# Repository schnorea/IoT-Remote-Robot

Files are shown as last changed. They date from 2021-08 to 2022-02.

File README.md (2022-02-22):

# IoT-Remote-Robot


This quick and dirty IoT enabled InfraRed Remote control is a way to remotely control a Robosapien Robot. It uses a web interface that looks like the remote control that comes with the Robosapien, AWS S3 to serve the web page, API Gateway receive the commands from the web remote, and processes these commands in a Lambda function that uses http to publish the command to an AWS IoT Core MQTT broker.  The Robot has a backpack that is 3D printed that hooks to its back.  Out of the backpack is a wire stalk that looks like a bent antenna that holds an IR LED and that connects to electronics in the backpack.  The IR stalk is pointed at the head of the Robosapien and directs the IR light to the IR receive located in the robots head.  Inside the backpack there is a driver circuit for the IR LED, a ESP8266 (Could easily be converted to a ESP32) that has a WIFI module. Flashed into the ESP8266 is firmware to access the local WIFI AP, create a secure connection to AWS IoT Core's MQTT broker and the logic to subscribe to the command messages originating in the Lambda function mentioned above. The backpack also contains the insides of a USB charging battery that has a lithium battery and the circuitry to charge from a 5 volt source and to provide 5 V to the ESP8266 and the IR LED. There are some diagrams, images and model renderings below.

## WARNING: This is a quick and dirty project. Normal engineering rigor and cyber security has not been applied here and your UX might vary.

## Background
During Covid my nephew, who lives across the state from me, was getting bored couped up at home with my sister. I would call and facetime and we would crack jokes to each other but couldn't really play together. I was thinking about how we could make it so we could remotely play and thought of those things in my house that could be remotely controlled.  I had gotten the Robosapien as a gag gift years ago for Christmas and this project was born.

## Remote Play Use Case
The way my nephew and I would use this is as follows.  
 * I would text my nephew the URL for the web remote.  
 * Once he had the remote up on his phone I would Facetime/Zoom him and he would answer on his iPad/Laptop. 
 * I would turn on the Robosapien and his IoT Backpack and let it connect to the Wifi and then to AWS.  When the backpack glowed blue (LED in the ESP8266) I knew it was connected.
 * I would give the thumbs up to my nephew and turn my phone with Facetime or laptop with Zoom running on it so that he could see the robot.
 * My nephew would then begin to control the robot remotely and laughing would ensue.

## Block Diagram
Here you can see the system block diagram.  

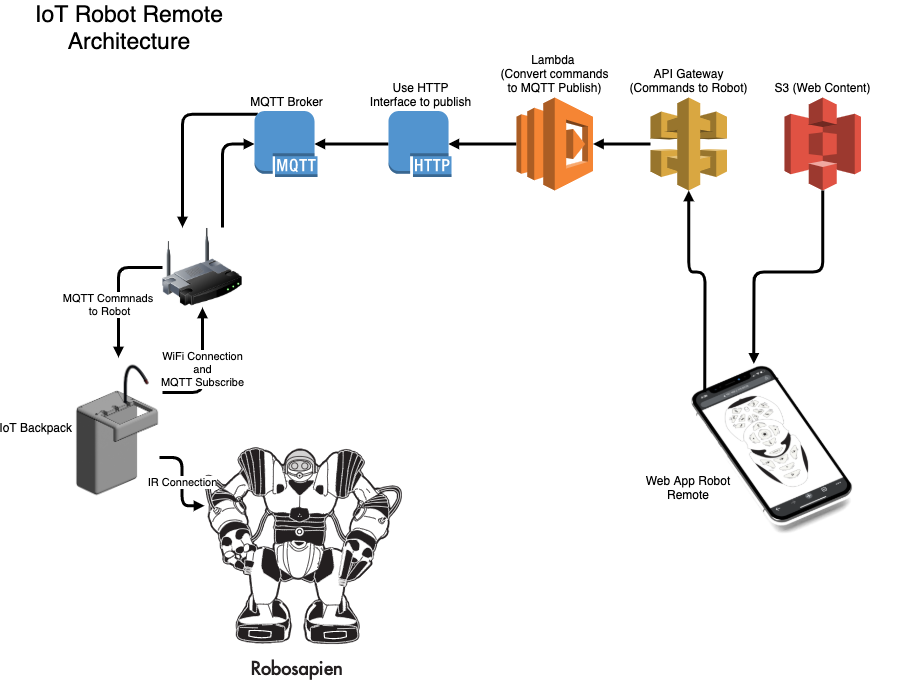
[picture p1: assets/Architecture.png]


## The Remote
The remote is assembled from very basic web tech.  HTML, SVG, Javascript, AJAX and a bit of CSS. Each button of the remote, in the SVG, has the code associated with the three modes the remote can be in attached.  With a click event the Javascript pulls the correct IR code from the button and performs a get to the AWS API Gateway.  You will need to setup your own API gateway for your own robot.  

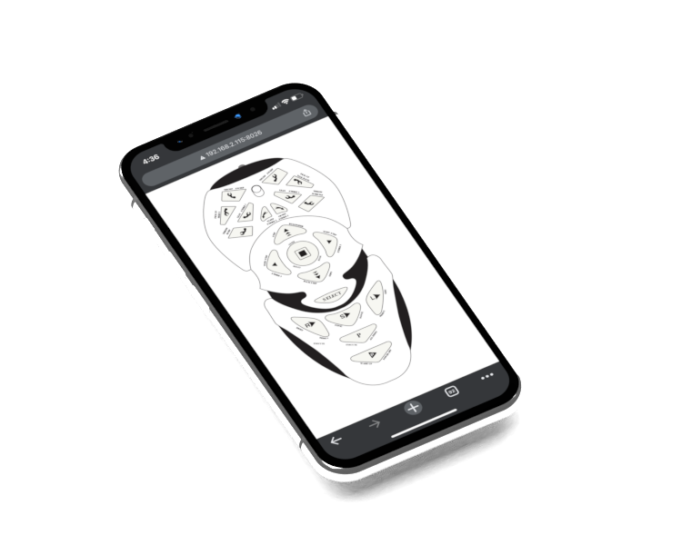
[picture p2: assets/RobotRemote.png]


## AWS
In AWS we use S3 to host and server the Web Remotes content.  S3 can be setup to server content by allowing it to be exposed publicly.  Again, this isn’t meant to be a product and is something that isn’t running all the time so quick and dirty.

Commands from the Web Remote are received via an API Gateway.  The gateway is configured to recognize the GET method which then triggers a Lambda function.

The Lambda function’s job is to take the Remote commands received via API Gateway and to publish them to the MQTT broker.  Yes, I could have cut out the Lambda function by doing MQTT over websockets but I didn’t want to have to have my Nephew have to sign-in to access the Web Remote.

The IoT Core MQTT broker is setup with a policy that allows commands to by publish and subscribed to.  It also has authentication and encryption enabled.  This is perhaps the most secure part of the pipeline. It also means that the backpack has to have credentials to communicate with the MQTT broker.

## The Backpack
As mentioned above the backpack is built around a ESP8266 Wifi module I ordered from Amazon (~$6.00).  Around the module are circuitry for the IR LED transmitter, a lithium battery and charging system I stole from a cell phone charging battery.  This is housed in a 3D printed case that was partially designed for this application and partially borrowed from a light dimming project.

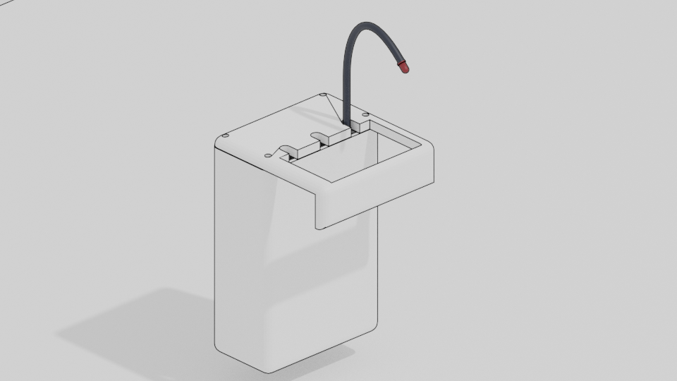
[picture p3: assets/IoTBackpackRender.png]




### The Ugly Electronics
Again as this was meant to be quick and dirty nothing elegent was designed to make this remotely pretty.  Old wire wrap board with hand soldered components and the piece de resistance(sp) the power supply assembly.







### Time to assemble.
As I had everything in the basement the hardware didn't take long to build. So, maybe 3 hours which included destroying the battery charger and making everything fit.

## Possible Improvements
 * The ESP8266 has barely enough computational power to run this app. I think the problem is the encryption overhead.  As a result of this the IoT backpack sometimes takes a long time to connect as it times out due to potentially poor comms making the computation take longer. (Anecdotally, it seems to connect better with a better WiFi signal). Improvement would be to port it to ESP32 which I don’t believe will have this problem.
 * I think there is just enough performance in an ESP32-CAM to do both the IoT function and stream the video so one idea would be to incorporate the video stream in the Web Remote interface.  This would simplify the use and also mean that the player would have a robot's eye view (First Person Robot?).
 * Make the Web Remote a true web app for iOS. On other projects I have done, if you add the correct meta fields and icons information into the web pages header you can create something that looks and feels a lot like a iPhone app without all the hassle of diving into XCode or other platforms. With a save to homepage bookmark from Saferi it presents itself as an ordinary app icon.

## Other uses
Since building this and having my nephew remotely come over and play a couple of other uses cases have presented themselves. 
 * Change channels of TV at home.  Why?
 * Turn on Air condition before getting home. Some AC units have IR remotes.
 * Attach it to other IR controlled toys.
 * IoT Slot cars.
 * If you have other ideas open an issue.

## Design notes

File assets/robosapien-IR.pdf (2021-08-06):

Interfacing a Robosapien with a mote

The commands to control the robosapien are sent from the IR transmitter to the receiver to the main control board as a sequence of 8 bits (most significant bit first). These bits are encoded using a space coded signal. The space coding works as follows:
- Default signal state: high
- Start: signal goes low for 8/1200 seconds
- Data bits (sequence of 8):
- 0: signal high for 1/1200s and low for 1/1200s
- 1: signal high for 4/1200s and low for 1/1200s

The IR control can be skipped by directly interfacing the microcontroller (mote) with the robosapien main control board.

Detailed | commands | from: | http://www.andrew.cmu.edu/user/ebuehl/robosapien-
lirc/ir_codes.htm

Movement Commands (no shift)

- $80 - turn right (on left side of remote)
- $81 - right arm up (upper left button on remote)
- $82 - right arm out
- $83 - tilt body right
- $84 - right arm down
- $85 - right arm in
- $86 - walk forward
- $87 - walk backward
- $88 - turn left (on right side of remote)
- $89 - left arm up (upper right button on remote)
- $8A - left arm out
- $8B - tilt body left
- $8C - left arm down
- $8D - left arm in
- $8E - stop

Programming Commands (no shift)

- $90 - P (Master Command Program)
- $91 - P>> (Program Play, the one on the bottom)
- $92 - R>> (Right sensor program)
- $93 - L>> (Left sensor program)
- $94 - S>> (Sonic sensor program)

GREEN shift commands

- $A0 - right turn step
- $A1 - right hand thump
- $A2 - right hand throw
- $A3 - sleep
- $A4 - right hand pickup
- $A5 - lean backward
- $A6 - forward step
- $A7 - backward step
- $A8 - left turn step
- $A9 - left hand thump
- $AA - left hand throw
- $AB - listen
- $AC - left hand pickup
- $AD - lean forward
- $AE - reset
- $B0 - Execute (master command program execute)

- $B1 - Wakeup
- $B2 - Right (right sensor program execute)
- $B3 - Left (left sensor program execute)
- $B4 - Sonic (sonic sensor program execute)

ORANGE shift commands

- $C0 - right hand strike 3
- $C1 - right hand sweep
- $C2 - burp
- $C3 - right hand strike 2
- $C4 - high 5
- $C5 - right hand strike 1
- $C6 - bulldozer
- $C7 - oops (fart)
- $C8 - left hand strike 3
- $C9 - left hand sweep
- $CA - whistle
- $CB - left hand strike 2
- $CC - talkback
- $CD - left hand strike 1
- $CE - roar
- $D0 - All Demo
- $D1 - Power Off (drop snow-globe and say "Rosebud")
- $D2 - Demo 1 (Karate skits)
- $D3 - Demo 2 (Rude skits)
- $D4 - Dance

NOTES:

- add $08 to go from right-side commands to left-side commands.
- add $20 to command bytes for the GREEN shift (ie. $Ax and $Bx range)
- add $40 to command bytes for the ORANGE shift (ie. $Cx and $Dx range)

SECRET UNDOCUMENTED CODES

Several different launch codes (Executing the main program)

- $B0 - standard "EXECUTE" on remote
Robot says "uh-huh" before starting Main program
No subroutines called [Execute sensor commands (Green Shift) cause error sounds to be played instead of what they should do -- bug or feature you decide]
- $97 - appears to be same as $B0
- $98 - Quiet execute main program
Robot does not say "uh-huh"
No subroutines called

- $9A - Quiet execute main program with subroutines !!
Robot does not say "uh-huh"
Subroutines are called (as documented in the manual). This is the one to use. Execute feature appears to be same as $91 (regular remote Program Play). $91 button also does other things like end the current recording. $9A code doesn't.

Useful? secret codes

- $F6 - feet shuffle
- $FB - nothing (useful as NO-OP)
- $FC - raise arm throw
- $D6 - karate chop

WORK IN PROGRESS, not useful [or at least no significant difference detected]

- $95,$96 - Program main again (like $90)
- $99 - like $98
- $9B - like $90 ?
- $9C - do nothing
- $9D,9E,9F - like $90 ?
- $B5 - like $97 ?
- $B6 - like $90 ?
- others - looks like these repeat as well (eg: record/execute one of the program areas) or do nothing
- $E0 - $EE (looks like the $A0 range)
- $EF - nothing
- $F0 - like $97
- $F1 - like $98
- $F2 - Execute right program
- $F3 - Execute left program
- $F4 - Execute sonic program
- $F5 - like $F0/97 ?
- $F7 - like $F0/97 ?
- $F8,F9,FA - like $F1/98 ?
- $FD,FE,FF - program main again (like $90)

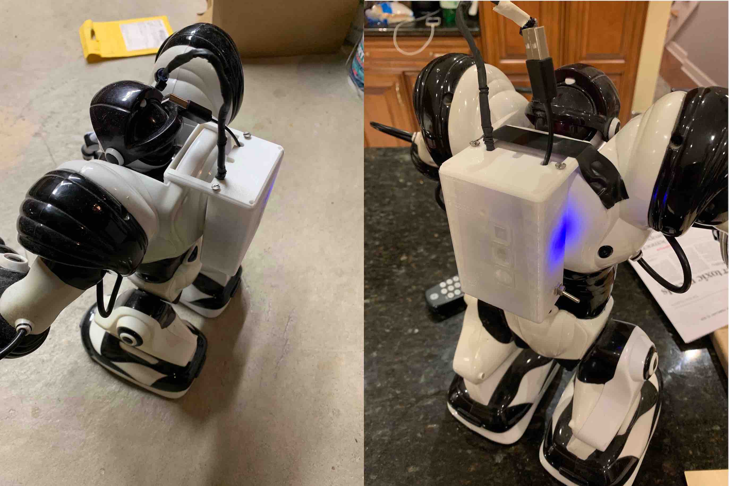
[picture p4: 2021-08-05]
assets/robotview_all.jpg

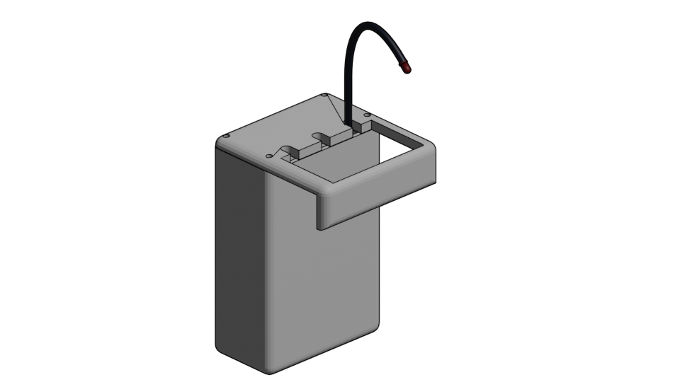
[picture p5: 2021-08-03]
assets/BackPackRender.png

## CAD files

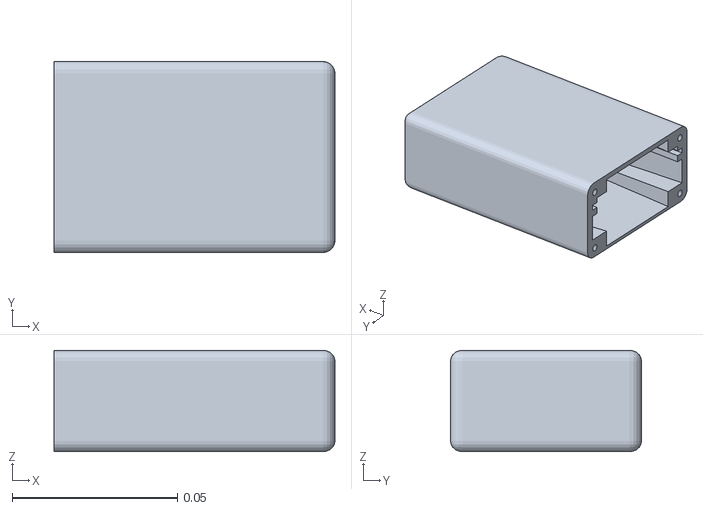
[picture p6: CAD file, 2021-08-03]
stls/Backpack-box.stl
0.0849 x 0.0578 x 0.0306

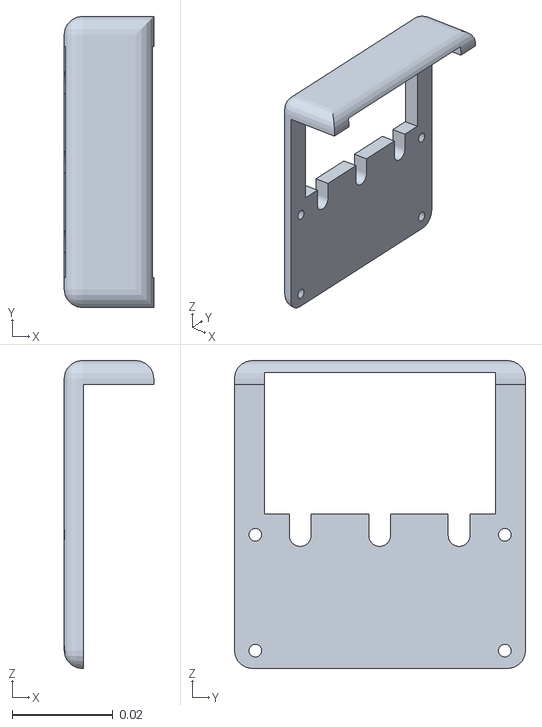
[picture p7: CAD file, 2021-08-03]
stls/Backpack-straps.stl
0.0178 x 0.0578 x 0.0611

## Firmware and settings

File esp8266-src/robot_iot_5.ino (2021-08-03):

#include <ESP8266WiFi.h>
#include <WiFiClientSecure.h>
#include <MQTT.h>
#include <time.h>
#include "robosend.h"

#include "secrets.h"

#define emptyString String()

WiFiClientSecure net;

BearSSL::X509List cert(cacert);
BearSSL::X509List client_crt(client_cert);
BearSSL::PrivateKey key(privkey);

MQTTClient client(32);

time_t now;
time_t nowish = 1510592825;

void NTPConnect(void)
{
  Serial.print(F("Setting time using SNTP"));
  configTime(TIME_ZONE * 3600, DST * 3600, "pool.ntp.org", "time.nist.gov");
  now = time(nullptr);
  while (now < nowish)
  {
    delay(500);
    Serial.print(F("."));
    now = time(nullptr);
  }
  Serial.println(F("done!"));
  struct tm timeinfo;
  gmtime_r(&now, &timeinfo);
  Serial.print(F("Current time: "));
  Serial.print(asctime(&timeinfo));
}

void connectToWiFi(String init_str)
{
  if (init_str != emptyString)
    Serial.print(init_str);
  while (WiFi.status() != WL_CONNECTED)
  {
    Serial.print(F("."));
    delay(1000);
  }
  if (init_str != emptyString)
    Serial.println(F("ok!"));
}

void connectToMqtt() {
  while (!client.connect(THINGNAME)) {
    Serial.print(".");
    delay(1000);
  }
  Serial.println("\nconnected!");
  client.subscribe(MQTT_SUB_TOPIC);
}

void checkWiFiThenMQTT(void)
{
  connectToWiFi(F("Checking WiFi"));
  connectToMqtt();
}

#define LED 2  //On board LED

void messageReceived(String &topic, String &payload)
{
  digitalWrite(LED,0);
  Serial.println("Received [" + topic + "]: " + payload);
  
  char robo_cmd_str[sizeof(payload)];
  payload.toCharArray(robo_cmd_str, sizeof(robo_cmd_str));

  u_char robo_cmd = (u_char)strtol(robo_cmd_str, NULL, 16);
    
  robo_send(robo_cmd);
  digitalWrite(LED,1);
}

void changeState()
{
  digitalWrite(LED, !(digitalRead(LED)));  //Invert Current State of LED  
}

void setup()
{
  pinMode(LED,OUTPUT);
  digitalWrite(LED,1);
  
  Serial.begin(115200);
  delay(500);
  Serial.println("");
  Serial.println("RUN SETUP");
  Serial.print("D2 is");
  Serial.println(D2);
  
  WiFi.hostname(THINGNAME);
  WiFi.mode(WIFI_STA);
  WiFi.begin(ssid, pass);
  
  connectToWiFi(String(F("Attempting to connect to SSID: ")) + String(ssid));

  NTPConnect();
  
  net.setTrustAnchors(&cert);
  net.setClientRSACert(&client_crt, &key);
  
  client.begin(MQTT_HOST, MQTT_PORT, net);
  client.onMessage(messageReceived);
  
  print_info();
  
  Serial.println(F("Start MQTT Setup *******"));
  connectToMqtt();
  Serial.println(F("MQTT Setup DONE *******"));
  
  digitalWrite(LED,0);
  ESP.wdtFeed();
  delay(1000);
  ESP.wdtFeed();
  delay(1000);
  ESP.wdtFeed();
  delay(1000);
  ESP.wdtFeed();
  delay(1000);
  ESP.wdtFeed();
  digitalWrite(LED,1);
  
  Serial.println(F("Start Robo IR Setup *******"));
  robo_setup();
  Serial.println(F("Robo IR Setup DONE*******"));
}

int led_count = 0;

void loop()
{
  if (!client.connected())
  {
    Serial.print(F("Not Connected"));
    checkWiFiThenMQTT();
  }
  else
  {
    client.loop();
    delay(10);
    
    led_count++;
    if (led_count < 50) {
      digitalWrite(LED, 0);
    }
    else {
      digitalWrite(LED, 1);
    }
    if (led_count > 750) {
      led_count = 0;
    }
  }
}

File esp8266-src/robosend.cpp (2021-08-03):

#include <ESP8266WiFi.h>
#include "robosend.h"

#define LED_PIN D2

#define TIMER1_WRITE_VALUE 867

bool isLEDOn = false;

#define PIN_HIGH false
#define PIN_LOW true

#define START_WAIT 520
#define ONE_WAIT 260
#define ZERO_WAIT 65
#define BIT_WAIT 65

#define TX_IDLE 0x00
#define TX_START 0x80
#define TX_START_BIT 0x40
#define TX_BIT_HIGH 0x20
#define TX_BIT_LOW 0x10

volatile u_char tx_state = TX_IDLE;
volatile u_char tx_byte = 0;
volatile u_char tx_mask = 0x80;
volatile int tx_count = 0x00;

bool tx_pin_state = PIN_HIGH;

void tx_send(u_char byte_to_send)
{
    while (tx_state != TX_IDLE);
    tx_byte = byte_to_send;
    tx_mask = 0x80;
    tx_count = START_WAIT;
    tx_state = TX_START;
}

void ICACHE_RAM_ATTR tx_start_bit()
{
    tx_pin_state = PIN_HIGH;
    if (!tx_mask)
    {
        tx_state = TX_IDLE;
        return;
    }
    if (tx_byte & tx_mask) {
        tx_count = ONE_WAIT;
    }
    else {
        tx_count = ZERO_WAIT;
    }
    tx_state = TX_BIT_HIGH;
}

void ICACHE_RAM_ATTR tx_bit()
{
    tx_count -= 1;
    if (tx_state == TX_BIT_HIGH && tx_count < 0)
    {
        tx_pin_state = PIN_LOW;
        tx_count = BIT_WAIT;
        tx_state = TX_BIT_LOW;
    }
    if (tx_state == TX_BIT_LOW && tx_count < 0)
    {
        tx_pin_state = PIN_HIGH;
        tx_mask >>=1; 
        tx_state = TX_START_BIT;
    }
}

void ICACHE_RAM_ATTR tx_start() 
{
    tx_pin_state = PIN_LOW;
    tx_count -= 1;
    if (tx_count < 0)
    {
        tx_state = TX_START_BIT;
    }
}

void ICACHE_RAM_ATTR tx_state_machine()
{
    if (tx_state == TX_IDLE)
    {
      
    }
    if (tx_state == TX_START)
    {
        tx_start();
    }
    if (tx_state == TX_START_BIT)
    {
        tx_start_bit();
    }
    if (tx_state == TX_BIT_HIGH || tx_state == TX_BIT_LOW)
    {
        tx_bit();
    } 
}

void robo_send(u_char robo_cmd)
{
    u_char cmd_check = robo_cmd;
    cmd_check >>= 4;
    if (cmd_check == 0x08 || cmd_check == 0x09 || cmd_check == 0x0A || 
        cmd_check == 0x0B || cmd_check == 0x0C || cmd_check == 0x0D )
    {
        tx_send(robo_cmd);
    }
    else 
    {
        Serial.println("Fail, command has to be in the range of 0x80 - 0xD0");
    }
    Serial.println(robo_cmd);
}

void robo_callback()
{    
    isLEDOn = !isLEDOn;
    tx_state_machine();
}

void ICACHE_RAM_ATTR onTimerISR(){
    // Interrupt service routine
    digitalWrite(LED_PIN, isLEDOn && tx_pin_state);

    isLEDOn = !isLEDOn;
    tx_state_machine();
    timer1_write(TIMER1_WRITE_VALUE); 
}

void robo_setup()
{
    pinMode(LED_PIN, OUTPUT);
    timer1_attachInterrupt(onTimerISR);
    timer1_write(TIMER1_WRITE_VALUE); 
    timer1_enable(TIM_DIV1, TIM_EDGE, TIM_LOOP);
}

void print_info()
{
    Serial.print("ESP.getBootMode(); ");
    Serial.println(ESP.getBootMode());
    Serial.print("ESP.getSdkVersion(); ");
    Serial.println(ESP.getSdkVersion());
    Serial.print("ESP.getBootVersion(); ");
    Serial.println(ESP.getBootVersion());
    Serial.print("ESP.getChipId(); ");
    Serial.println(ESP.getChipId());
    Serial.print("ESP.getFlashChipSize(); ");
    Serial.println(ESP.getFlashChipSize());
    Serial.print("ESP.getFlashChipRealSize(); ");
    Serial.println(ESP.getFlashChipRealSize());
    Serial.print("ESP.getFlashChipSizeByChipId(); ");
    Serial.println(ESP.getFlashChipSizeByChipId());
    Serial.print("ESP.getFlashChipId(); ");
    Serial.println(ESP.getFlashChipId());
    Serial.print("ESP.getFreeHeap(); ");
    Serial.println(ESP.getFreeHeap());
}
